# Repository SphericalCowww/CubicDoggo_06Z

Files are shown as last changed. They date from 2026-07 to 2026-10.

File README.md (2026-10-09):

# CubicDoggo 06Z: Homemade 12-DOF 4-Legged Robot Recipe with Simulation and Reinforcement Learning

Cubic Doggo 06Z Neucommu is upgraded from [Cubic Doggo 06R High Mobility](https://github.com/SphericalCowww/CubicDoggo_06R). The goal is to integrate a simulation (Gazebo/Mujoco) and reinforcement learning (PyTorch) to control walking gait. 

Demos: Gazebo with Plotjuggler ([Reddit](https://www.reddit.com/r/ROS/comments/1vomb40/cubic_doggo_update_on_gazebo/)), Gazebo sim vs real ([Reddit](https://www.reddit.com/r/robotics/comments/1vpu2sd/cubic_doggo_found_a_nice_spot_on_the_ramp/)), MuJoCo sim ([Reddit](https://www.reddit.com/r/ROS/comments/1w8vm74/cubic_doggo_update_ros2_bridge_to_mujoco/), Pinocchio walk ([Reddit](https://www.reddit.com/r/robotics/comments/1wgilv9/cubic_doggo_ik_walking_with_pinocchio/)

## Moment of inertia from FreeCAD

To get the moment of inertia for a FreeCAD piece, run,

    # open FreeCAD > View > Panels > Python console
    obj = App.ActiveDocument.getObject("Body")
    shape = obj.Shape
    print(shape.Mass)
    print(shape.CenterOfMass)
    print(shape.MatrixOfInertia)

Then use this formula to convert to URDF value for each matrix element (I: moment of inertia, M: mass):

    I_urdf = I_freeCAD*(M_physical/M_freeCAD)*1.0E-6

The convex mesh can also be included for collision geometry; check out ``batteryHolder`` under ``CubicDoggo_06Z/src/my_robot_description/urdf/cubic_doggo.gazebo.xacro``.

Don't forget to check the basic geometry under rViz first:

    cd CubicDoggo_06Z
    colcon build
    source install/setup.bash
    ros2 launch my_robot_description cubic_doggo.rviz.launch.xacro.py

## Gazebo

To have a window for keyboard control:

    sudo apt install xterm

Reminder that ``~/.gz/sim/8/gui.config``contains GUI display options, such as camera location. Then run:

    cd CubicDoggo_06Z
    colcon build
    source install/setup.bash
    ros2 launch my_robot_bringup cubic_doggo.gazebo.with_lifecycle.launch.py
    ros2 run plotjuggler plotjuggler      # on another terminal

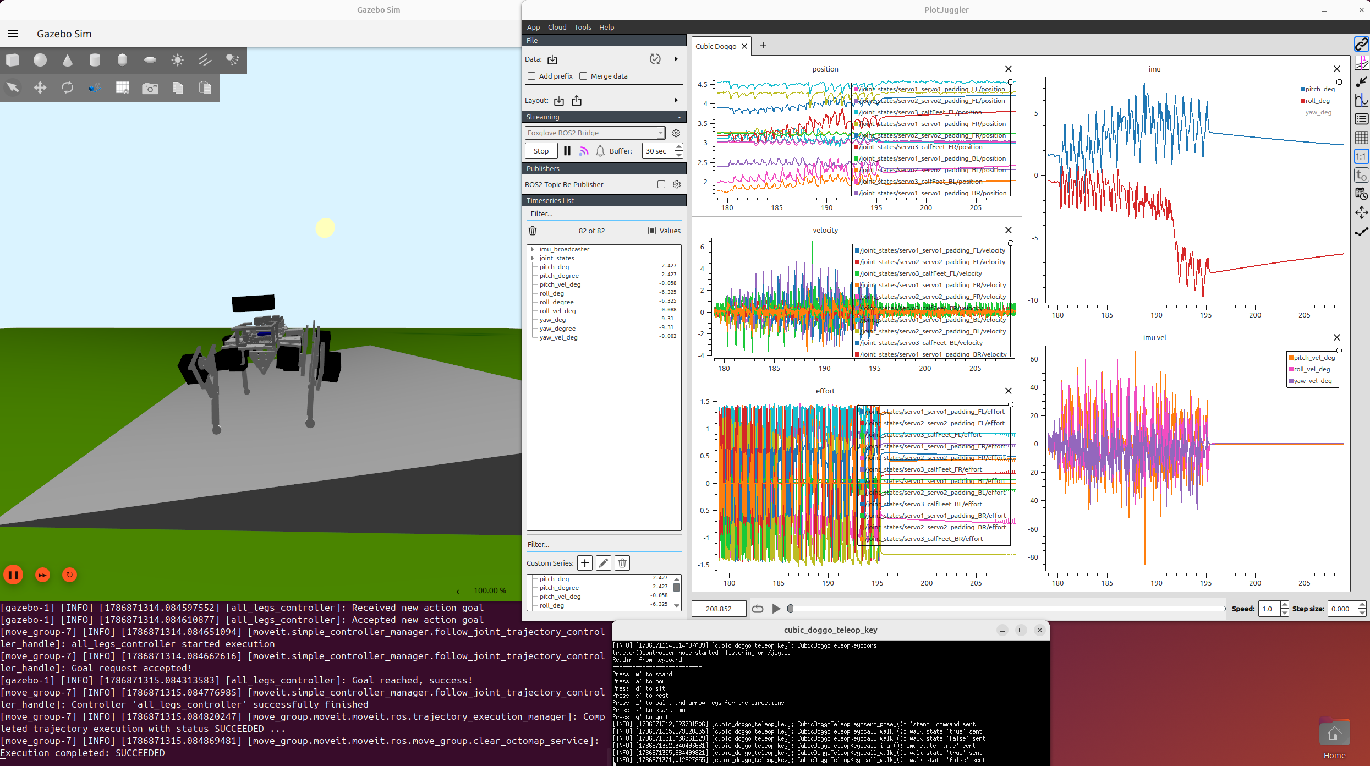
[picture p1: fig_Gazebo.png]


In the figure, the robot walks up the ramp, stands, turns on the IMU, walks with IMU, and then just stands with IMU on:

  * top-left: Gazebo graphics
  * top-right: plotjuggler
    * left: all 12 servo positions, velocities, and loads set to 1.5N limit
    * right: IMU values (PID control to make roll (tilt left-sideways) and pitch (tilt backward) to 0) and their velocities
  * bottom-left: launch terminal outputs
  * bottom-center: xterm control command window

Adding the following line of 20 ms delay in IMU does cause oscillatory behavior in Gazebo sometimes (turn off for real robot!):

    vim CubicDoggo_06Z/src/my_robot_commander/src/cubic_doggo_lifecycle_imu.cpp 
    # std::this_thread::sleep_for(std::chrono::milliseconds(20)); // WARNING: deliberate delay for simulation!!!

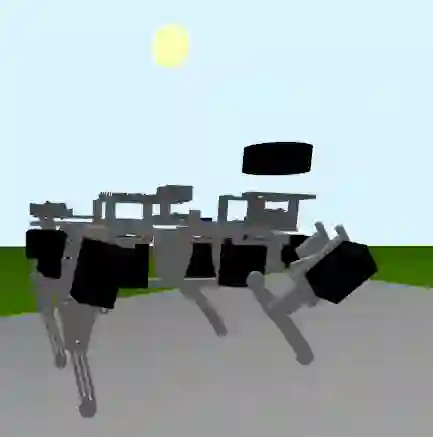
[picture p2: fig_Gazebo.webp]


## PyBullet

    cd CubicDoggo_06Z/
    cd ..                                                              # do NOT make the CubicDoggo_06Z_env/ inside CubicDoggo_06Z/, it will mess up colcon build
    python3 -m venv CubicDoggo_06Z_env/
    source CubicDoggo_06Z_env/bin/activate
    pip install --upgrade pip
    pip install "numpy<2"
    pip install setuptools jinja2 pyyaml typeguard
    pip install pybullet 
    pip install pin                                                     # for pinocchio
    pip install torch gymnasium stable-baselines3
    python3 -c "import torch; import pinocchio; import pybullet; import stable_baselines3; print('Installation Successful')"
    cd CubicDoggo_06Z/
    colcon build
    source install/setup.bash

Halfway through, realized MuJoCo is the modern way for robot simulation in python with CPU.

## MuJoCo

MuJoCo is a physics simulator like Gazebo,

    cd CubicDoggo_06Z/
    cd ..                                                                # do NOT create the CubicDoggo_06Z_env/ inside CubicDoggo_06Z/, it will mess up colcon build
    python3 -m venv CubicDoggo_06Z_env/
    source CubicDoggo_06Z_env/bin/activate
    export PYTHONPATH=$PYTHONPATH:.../CubicDoggo_06Z_env/lib/python3.12/site-packages     # put it in .bashrc
    export PYTHONPATH=$PYTHONPATH:.../CubicDoggo_06Z_env/lib/python3.12/site-packages/cmeel.prefix/lib/python3.12/site-packages
    pip install --upgrade pip 
    pip install catkin_pkg empy lark
    pip install jinja2 pyyaml typeguard setuptools wheel
    pip install mujoco pin gymnasium torch stable-baselines3 tensorboard            # pin for pinocchio
    pip install onnx onnxscript onnxruntime
    pip install --upgrade opencv-python
    python3 -c "import mujoco; import pinocchio; import gymnasium; import torch; import stable_baselines3; print('Installation Successful')"
    cd CubicDoggo_06Z/
    rm -r install/ build/ log/
    colcon build
    source install/setup.bash

### Launch MuJoCo with ROS2

To have 1 leg for the MuJoCo test, run:

    cd CubicDoggo_06Z/
    source ../CubicDoggo_06Z_env/bin/activate
    colcon build --cmake-clean-first
    source install/setup.bash
    ros2 run my_robot_commander_py cubic_leg1_mujoco_init
    # toggle 1 for visual, and toggle 0 for collision
    # expand control on the right-hand side to change joint values

To have the full robot with IMU as output, run:

    ros2 run my_robot_commander_py cubic_doggo_mujoco_init

To launch with commander/controller:
    
    ros2 launch my_robot_commander_py cubic_doggo.mujoco.with_lifecycle.launch.py
    ros2 run plotjuggler plotjuggler      # on another terminal

Note that this ROS2 to MuJoCo bridge does not use mujoco_ros2_control, but action server and joint state publisher instead. The reaction should rightfully be slower and less deterministic, but MuJoCo is plenty fast that its speed actually needs to be tuned by actuator PID under ``CubicDoggo_06Z/src/my_robot_description/urdf/cubic_doggo.mujoco.xml``.

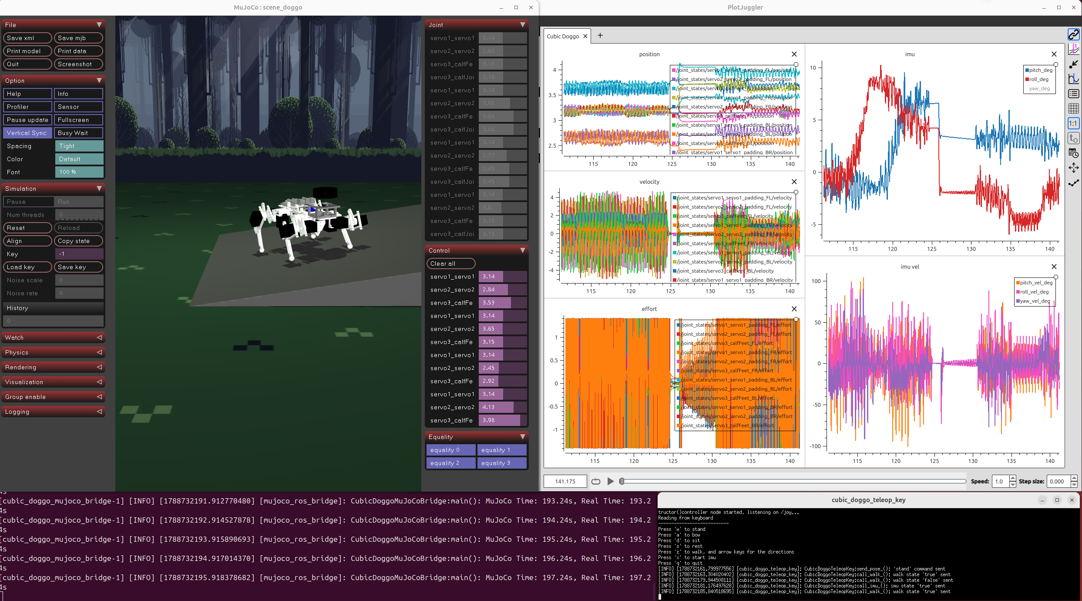
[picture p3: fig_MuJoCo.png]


Using the same ROS2 commander as for Gazebo.

### Launch MuJoCo with Pinocchio

Pinocchio is used as an IK solver to generate a predefined walk gait for later imitation learning,

    cd CubicDoggo_06Z/
    source ../CubicDoggo_06Z_env/bin/activate
    colcon build --cmake-clean-first
    source install/setup.bash
    ros2 run my_robot_commander_py cubic_doggo_mujoco_pin_stand_test
    ros2 run my_robot_commander_py cubic_doggo_mujoco_pin_walk
    ros2 run my_robot_commander_py cubic_doggo_mujoco_pin_stand

### Reinforcement learning with Gymnasium and stable-baselines3

Gymnasium sets up the environment for reinforcement learning, while stable-baselines3 provides the PPO optimization method for the reward/penalty terms from Gymnasium,

    cd CubicDoggo_06Z/
    source ../CubicDoggo_06Z_env/bin/activate
    colcon build --cmake-clean-first
    source install/setup.bash
    ros2 run cubic_doggo_mujoco_ppo_stand_train_kinematicHeight
    tensorboard --logdir=ppo_tensorboards
    # open in browser: http://localhost:6006

### Deploying model to MuJoCo

    cd CubicDoggo_06Z/
    source ../CubicDoggo_06Z_env/bin/activate
    colcon build --cmake-clean-first
    source install/setup.bash
    ros2 run my_robot_commander_py cubic_doggo_mujoco_ppo_stand_deploy

## References:

- CFD Intech, FreeCAD Tutorial | Exercise 6: How to Calculate Moment of Inertia of Model and Paste to Spreadsheet (<a href="https://www.youtube.com/watch?v=h6S0lKXxD3s">YouTube</a>)
- Edan Meyer | Proximal Policy Optimization (PPO) Explained ([YouTube](https://www.youtube.com/watch?v=HrapVFNBN64))

## Acknowledgements

- Some utility programs are adapted from the ROBOTIS DYNAMIXEL [Workbench examples](https://github.com/ROBOTIS-GIT/dynamixel-workbench/tree/main/dynamixel_workbench_toolbox/examples/sr) and [U2D2 Controller CAD](https://en.robotis.com/service/downloadpage.php?ca_id=70f0#). These files remain licensed under the Apache License 2.0. Modifications are documented in the source files.
- Raspberry Pi 5 CAD model sourced from [Printables](https://www.printables.com/model/607854-raspberry-pi-5).
- RPLIDAR A1M8 CAD model provided by [SLAMTEC](https://www.slamtec.com/en/support#rplidar-a-series).
- Forest background used in MuJoCo, "Free Pixel Art Forest" by edermuniz14 from [GameDev Market](https://www.gamedevmarket.net/asset/free-pixel-art-forest). Used under the GameDev Market Pro Licence.
- 8-bit AI-generated music by Retro-BGM-Chan from [Pixabay](https://pixabay.com/users/retro-bgm-chan-55246343/). Used under the [Pixabay License](https://pixabay.com/service/license-summary/)
- 8-bit AI-generated music by Brutaldesign from [Pixabay](https://pixabay.com/users/brutaldesign-52522998). Used under the [Pixabay License](https://pixabay.com/service/license-summary/)
- 8-bit AI-generated music by Psychronic from [Pixabay](https://pixabay.com/users/psychronic-13092015). Used under the [Pixabay License](https://pixabay.com/service/license-summary/)

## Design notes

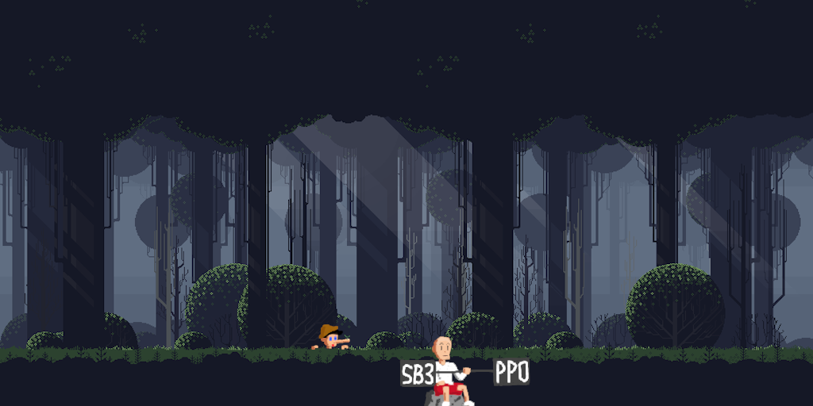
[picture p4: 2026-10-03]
src/my_robot_description/world/forest_gymnasium.png

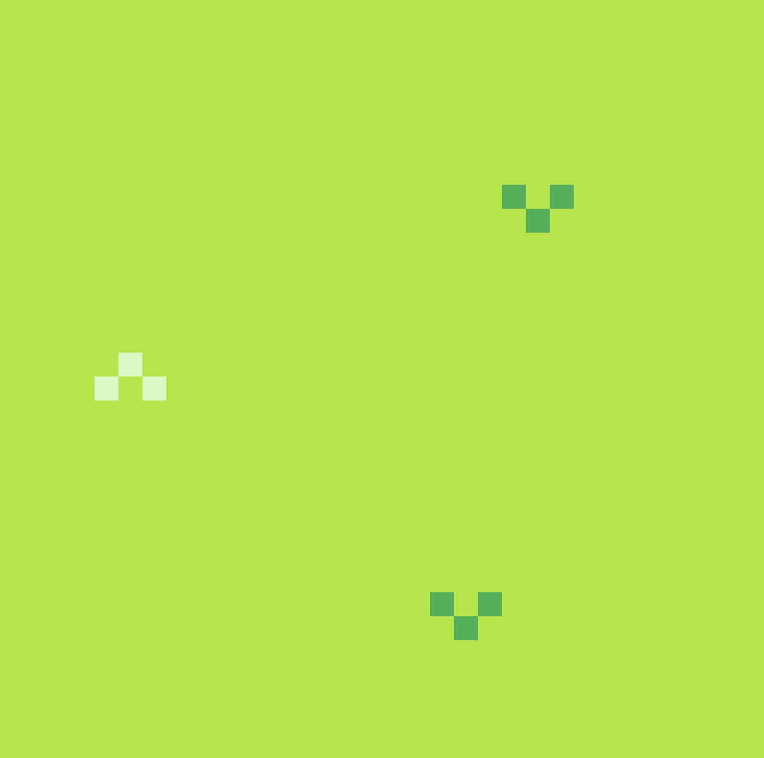
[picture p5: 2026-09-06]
src/my_robot_description/world/grass.png

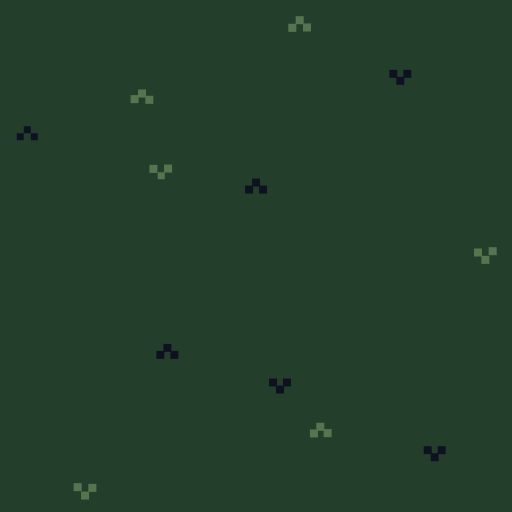
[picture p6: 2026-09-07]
src/my_robot_description/world/forest_floor.png

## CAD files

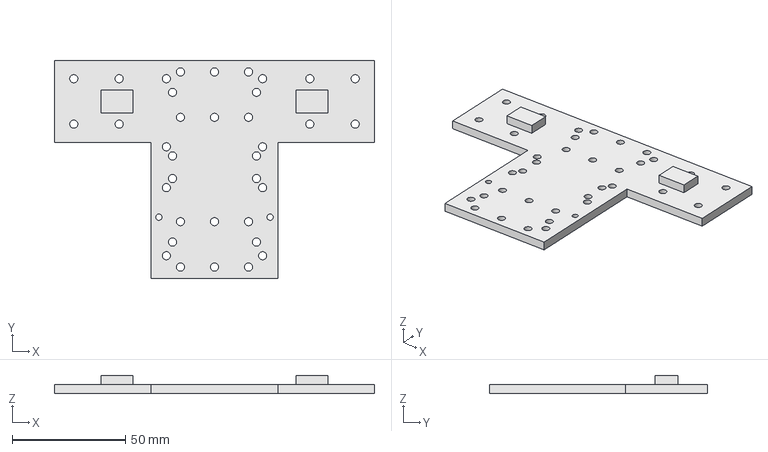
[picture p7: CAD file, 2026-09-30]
src/my_robot_description/mesh/CADv3/basePlate.FCStd
141.0 x 96.0 x 8.00 mm

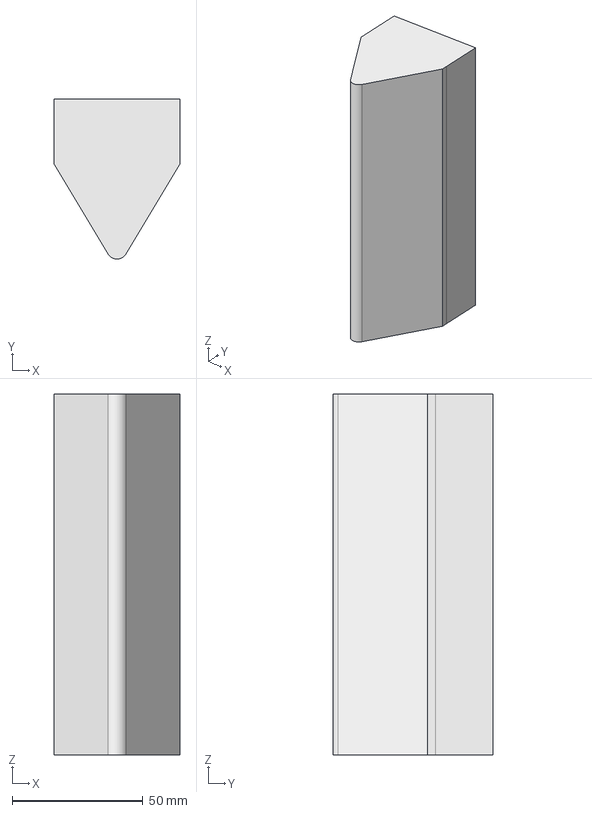
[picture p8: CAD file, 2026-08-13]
src/my_robot_description/mesh/collisionV3/batteryHolder.FCStd
48.0 x 61.2 x 138.0 mm

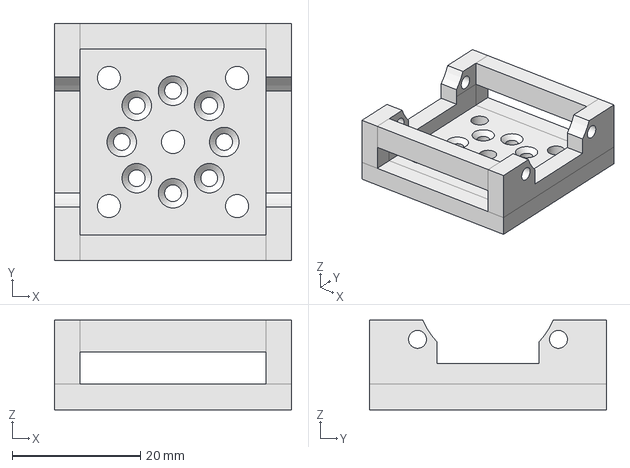
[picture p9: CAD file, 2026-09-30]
src/my_robot_description/mesh/CADv3/XL430holderBasic.FCStd
37.0 x 37.0 x 14.0 mm

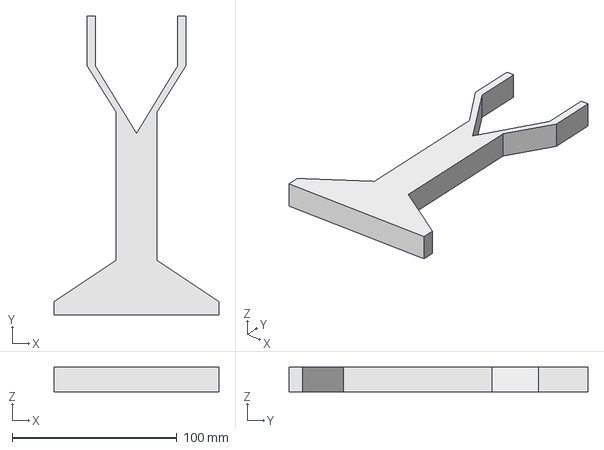
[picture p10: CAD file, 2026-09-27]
src/my_robot_description/mesh/CADv3/bodyHolder.FCStd
100.0 x 181.0 x 15.0 mm

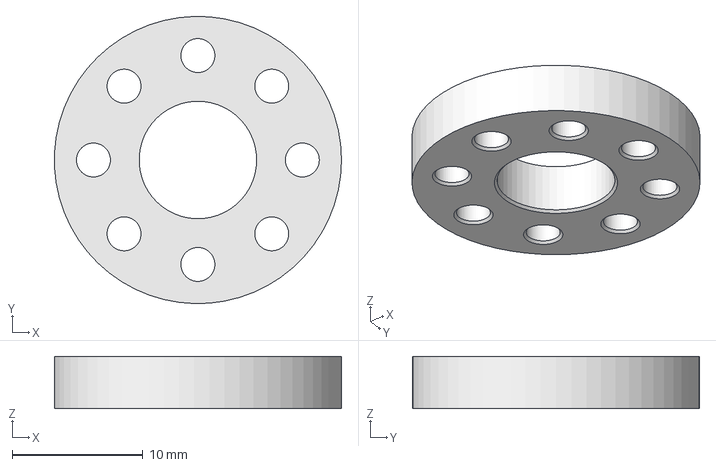
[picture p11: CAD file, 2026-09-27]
src/my_robot_description/mesh/CADv3/XL430rotorPadding.FCStd
22.0 x 22.0 x 4.00 mm

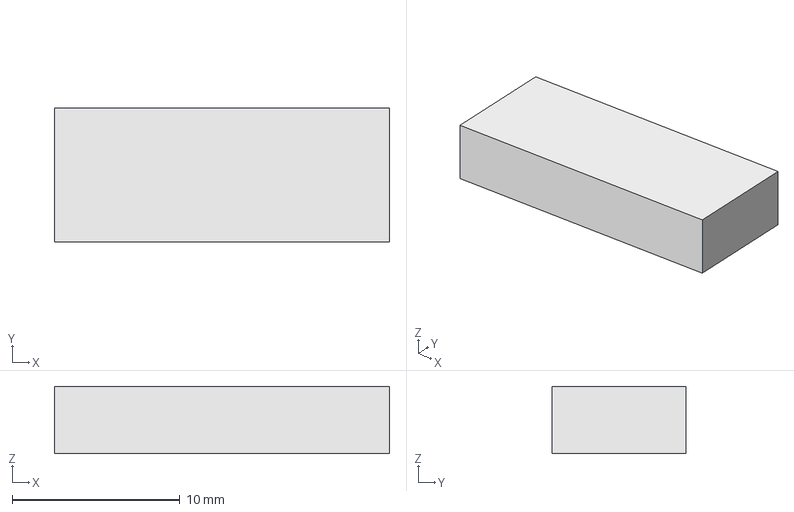
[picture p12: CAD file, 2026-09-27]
src/my_robot_description/mesh/CADv3/baseSticker.FCStd
20.0 x 8.00 x 4.00 mm

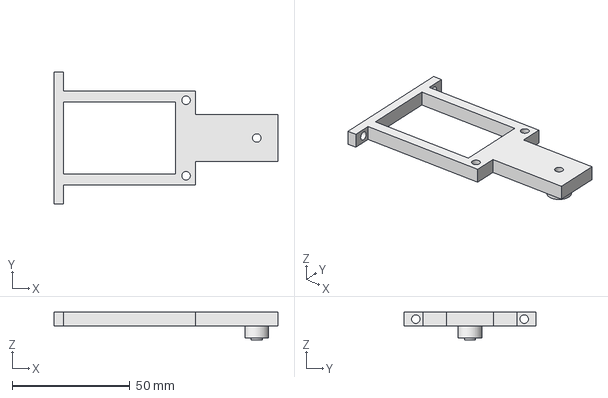
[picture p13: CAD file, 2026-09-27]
src/my_robot_description/mesh/CADv3/thighOuter.FCStd
95.0 x 56.0 x 11.8 mm

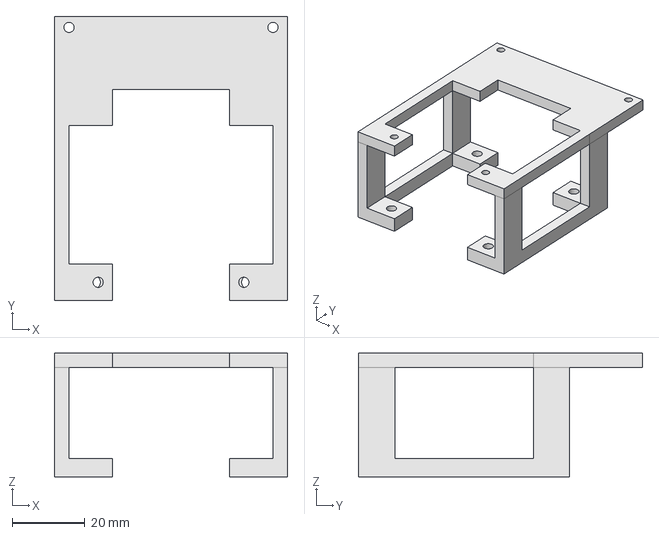
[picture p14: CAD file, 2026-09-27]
src/my_robot_description/mesh/CADv3/lidarHolder.FCStd
64.0 x 78.0 x 34.0 mm

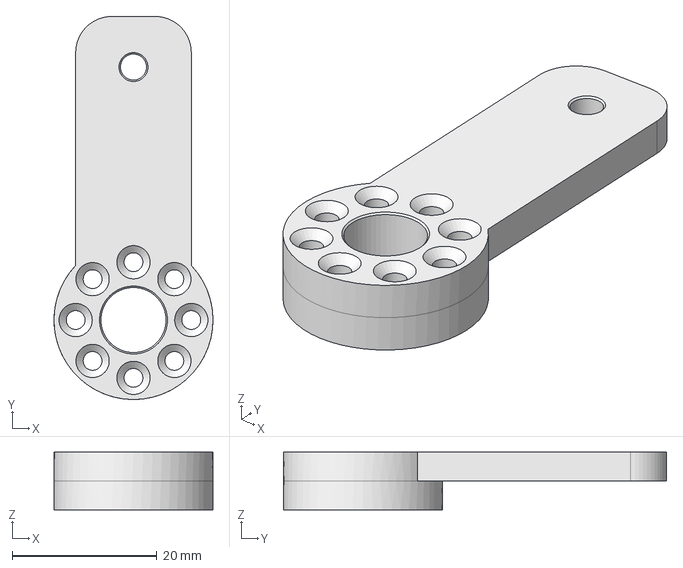
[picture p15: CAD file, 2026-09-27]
src/my_robot_description/mesh/CADv3/calfJoint.FCStd
22.0 x 53.0 x 8.00 mm

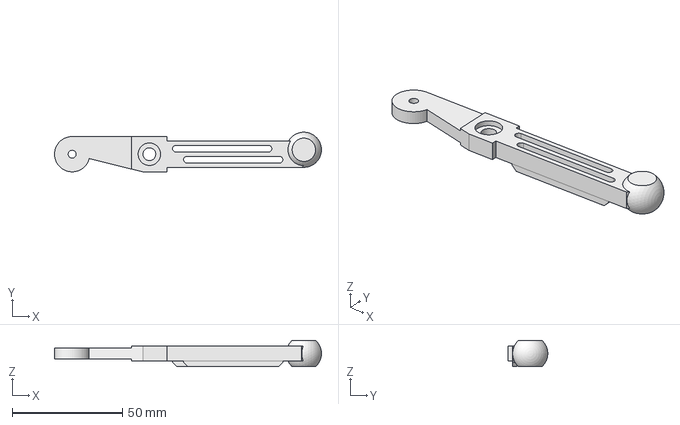
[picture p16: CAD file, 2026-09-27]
src/my_robot_description/mesh/CADv3/calfFeet.FCStd
121.0 x 18.0 x 12.0 mm

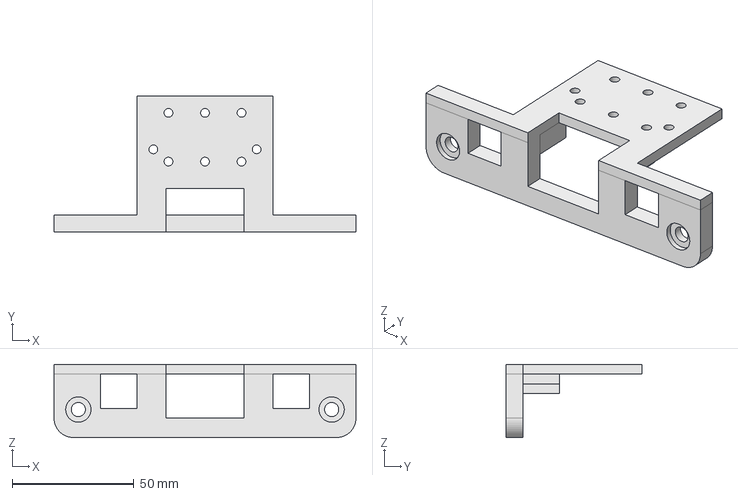
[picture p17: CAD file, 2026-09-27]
src/my_robot_description/mesh/CADv3/bearingPlate.FCStd
124.0 x 56.0 x 30.0 mm

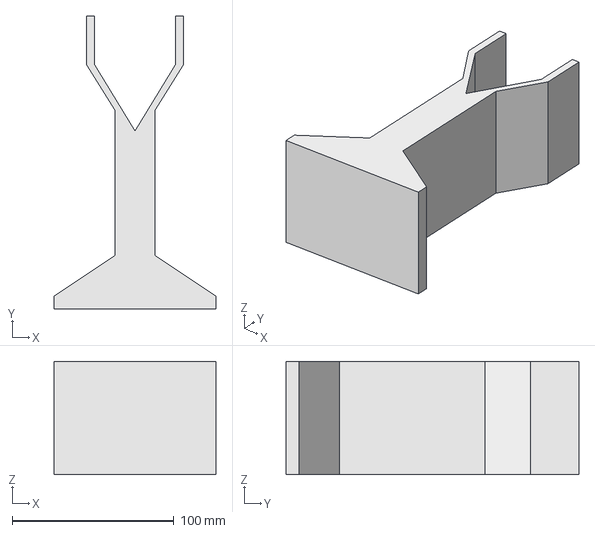
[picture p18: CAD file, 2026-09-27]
src/my_robot_description/mesh/CADv3/bodyHolderWide.FCStd
100.0 x 181.0 x 70.0 mm

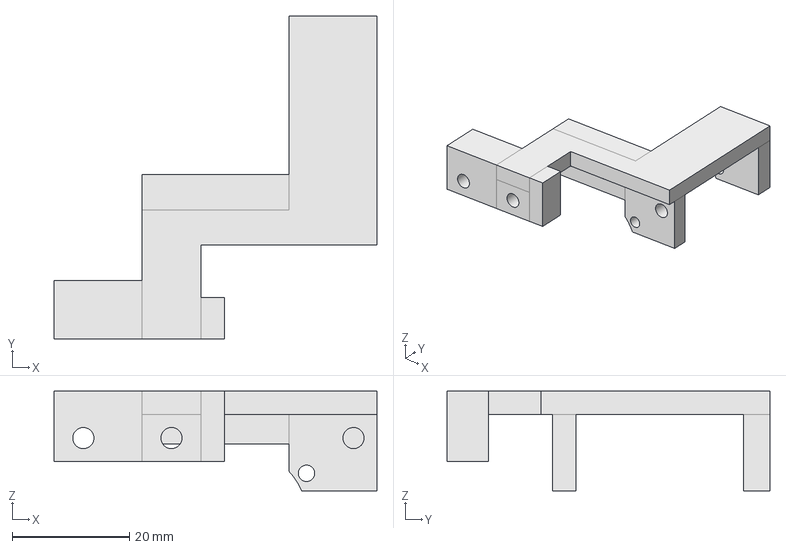
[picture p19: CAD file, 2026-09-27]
src/my_robot_description/mesh/CADv3/XL430holderThighBack.FCStd
55.0 x 55.0 x 17.0 mm

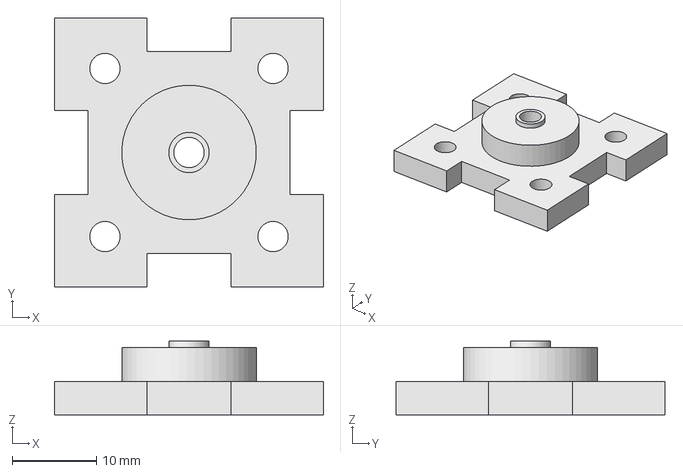
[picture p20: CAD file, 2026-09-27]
src/my_robot_description/mesh/CADv3/bearingPadding.FCStd
32.0 x 32.0 x 8.80 mm

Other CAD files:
src/my_robot_description/mesh/CADv3/thighInner.FCStd
src/my_robot_description/mesh/CADv3/fanFlag.FCStd
src/my_robot_description/mesh/CADv3/baseTorso.FCStd
src/my_robot_description/mesh/CADv3/XL430holderBasic.stl
src/my_robot_description/mesh/CADv3/XL430holderThighFront.FCStd
src/my_robot_description/mesh/CADv3/XL430rotorPadding.stl
src/my_robot_description/mesh/CADv3/basePlate.stl
src/my_robot_description/mesh/CADv3/baseTorso.stl
src/my_robot_description/mesh/CADv3/batteryHolder.FCStd
src/my_robot_description/mesh/CADv3/batteryHolder.stl
src/my_robot_description/mesh/CADv3/calfFeet.stl
src/my_robot_description/mesh/CADv3/calfFeetSpring.stl
src/my_robot_description/mesh/CADv3/calfJoint.stl
src/my_robot_description/mesh/CADv3/hdmiHolder.FCStd
src/my_robot_description/mesh/CADv3/lidarHolder.stl
src/my_robot_description/mesh/CADv3/thighInner.stl
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

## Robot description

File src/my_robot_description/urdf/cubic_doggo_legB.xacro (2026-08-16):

<?xml version="1.0"?>
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
<robot xmlns:xacro="http://www.ros.org/wiki/xacro">
    <xacro:macro name="doggo_legB" params="prefix">

    <xacro:property name="servo_x" value="0.0285"/>
    <xacro:property name="servo_y" value="0.0465"/>
    <xacro:property name="servo_z" value="0.034"/>
    <xacro:if value="${prefix == 'BL'}">
        <xacro:property name="rflc" value="-1"/>
        <xacro:property name="base_plate" value='base_plate_B'/>
        <xacro:property name="servo1_holder_xyz" value=" 0.052 0.018 0.004"/>
    </xacro:if>
    <xacro:if value="${prefix == 'BR'}">
        <xacro:property name="rflc" value=" 1"/>
        <xacro:property name="base_plate" value='base_plate_B'/>
        <xacro:property name="servo1_holder_xyz" value="-0.052 0.018 0.004"/>
    </xacro:if> 
    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
    <link name="servo1_holder_${prefix}">
        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
        <xacro:box_inertia m="0.0098" x="0.037" y="0.037" z="0.014" o_xyz="0 0 0.007" o_rpy="0 0 ${urdf_pi/2}"/>
    </link> 
    <joint name="base_plate_servo1_holder_${prefix}" type="fixed">
        <parent link="${base_plate}"/>
        <child link="servo1_holder_${prefix}"/>
        <origin xyz="${servo1_holder_xyz}" rpy="0 0 0"/>
    </joint>
    
    <link name="servo1_${prefix}">
        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
        <xacro:box_inertia m="0.0572" x="${servo_x}" y="${servo_y}" z="${servo_z}" o_xyz="0 0 ${servo_y/2}" o_rpy="${urdf_pi/2} 0 0"/>
    </link> 
    <joint name="servo1_holder_servo1_${prefix}" type="fixed">
        <parent link="servo1_holder_${prefix}"/>
        <child link="servo1_${prefix}"/>
        <origin xyz="0 0 0.008" rpy="0 0 0"/>
    </joint>

    <link name="servo1_padding_${prefix}">
        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
        <xacro:cylinder_inertia m="0.0013" r="0.011" l="0.004" o_xyz="0 -0.002 0" o_rpy="${urdf_pi/2} 0 0"/>
    </link> 
    <joint name="servo1_servo1_padding_${prefix}" type="revolute">
        <parent link="servo1_${prefix}"/>
        <child link="servo1_padding_${prefix}"/>
        <origin xyz="0 ${-servo_z/2-0.002} ${0.01+0.0025/2}" rpy="0 0 0"/>
        <axis xyz="0 -1 0"/>
        <limit effort="1.4" velocity="10.0" lower="${urdf_pi - urdf_pi/3}" upper="${urdf_pi + urdf_pi/3}"/>
        <dynamics friction="0.01" damping="0.1"/>
    </joint>

    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
    <link name="servo2_holder_${prefix}">
        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
        <xacro:box_inertia m="0.0098" x="0.037" y="0.037" z="0.014" o_xyz="0 -0.007 0" o_rpy="${urdf_pi/2} 0 0"/>
    </link> 
    <joint name="base_link_servo2_holder_${prefix}" type="fixed">
        <parent link="servo1_padding_${prefix}"/>
        <child link="servo2_holder_${prefix}"/>
        <origin xyz="0 -0.004 0" rpy="0 0 0"/>
    </joint>
    
    <link name="servo2_${prefix}">
        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
        <xacro:box_inertia m="0.0572" x="${servo_x}" y="${servo_y}" z="${servo_z}" o_xyz="0 ${-servo_y/2} 0" o_rpy="0 ${rflc*urdf_pi/2} 0"/>
    </link> 
    <joint name="servo2_holder_servo2_${prefix}" type="fixed">
        <parent link="servo2_holder_${prefix}"/>
        <child link="servo2_${prefix}"/>
        <origin xyz="0 -0.008 0" rpy="0 0 0"/>
    </joint>

    <link name="servo2_padding_${prefix}">
        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
        <xacro:cylinder_inertia m="0.0013" r="0.011" l="0.004" o_xyz="${rflc*0.002} 0 0" o_rpy="0 ${urdf_pi/2} 0"/>
    </link> 
    <joint name="servo2_servo2_padding_${prefix}" type="revolute">
        <parent link="servo2_${prefix}"/>
        <child link="servo2_padding_${prefix}"/>
        <origin xyz="${rflc*(servo_z/2+0.002)} -0.01125 0" rpy="0 0 0"/>
        <axis xyz="${rflc} 0 0"/>
        <limit effort="1.4" velocity="10.0" lower="${urdf_pi - 2*urdf_pi/6 + rflc*urdf_pi/6}" upper="${urdf_pi + 2*urdf_pi/6 + rflc*urdf_pi/6}"/>
        <dynamics friction="0.01" damping="0.1"/>
    </joint>

    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
    <link name="inner_thigh_${prefix}">
        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
        <xacro:box_inertia m="0.0085" x="0.032" y="0.040" z="0.006" o_xyz="${rflc*0.003} -0.016 0" o_rpy="${rflc*urdf_pi/2} 0 ${urdf_pi/2}"/>
    </link>
    <joint name="servo2_padding_inner_thigh_${prefix}" type="fixed">
        <parent link="servo2_padding_${prefix}"/>
        <child link="inner_thigh_${prefix}"/>
        <origin xyz="${rflc*0.004} -0.016 0" rpy="0 0 0"/>
    </joint>

    <link name="outer_thigh_${prefix}">
        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
        <xacro:box_inertia m="0.0113" x="0.040" y="0.032" z="0.006" o_xyz="${rflc*0.003} 0.0475 0" o_rpy="${-urdf_pi/2} ${urdf_pi/2-rflc*urdf_pi/2} ${-rflc*urdf_pi/2}"/>
    </link>
    <joint name="inner_thigh_outer_thigh_${prefix}" type="fixed">
        <parent link="inner_thigh_${prefix}"/>
        <child link="outer_thigh_${prefix}"/>
        <origin xyz="${rflc*0.028} 0 0" rpy="${urdf_pi} 0 0"/>
    </joint>

    <link name="servo3_${prefix}">
        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
        <xacro:box_inertia m="${0.0572+0.0113+0.0078}" x="${servo_x}" y="${servo_y}" z="${servo_z}" o_xyz="0 ${-servo_y/2} 0" o_rpy="0 ${rflc*urdf_pi/2} 0"/>
    </link>
    <joint name="outer_thigh_servo3_${prefix}" type="fixed">
        <parent link="outer_thigh_${prefix}"/>
        <child link="servo3_${prefix}"/>
        <origin xyz="${rflc*(servo_y/2-0.006-0.0025)} -0.004 0" rpy="0 0 0"/>
    </joint>

    <link name="calfFeet_${prefix}">
        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
        <xacro:box_inertia m="${0.0251-0.0080}" x="0.110" y="0.016" z="0.004" o_xyz="0 ${-0.008+0.008} ${0.035-0.050}" o_rpy="0 ${-urdf_pi/2} 0"/>
    </link>
    <joint name="servo3_calfFeet_${prefix}" type="revolute">
        <parent link="servo3_${prefix}"/>
        <child link="calfFeet_${prefix}"/>
        <origin xyz="${rflc*(-servo_z/2-0.002-0.0025)} ${-0.086+0.004} 0" rpy="${urdf_pi} 0 0"/>
        <axis xyz="${-rflc} 0 0"/>
        <limit effort="1.4" velocity="10.0" lower="${5*urdf_pi/8}" upper="${11*urdf_pi/8}"/>
        <dynamics friction="0.01" damping="0.1"/>
    </joint>

    <link name="calfJoint_${prefix}">
        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
        <xacro:box_inertia m="${0.0047+0.0015}" x="0.022" y="0.053" z="0.007" o_xyz="${-rflc*0.0005} 0 -0.0155" o_rpy="${-urdf_pi/2} 0 ${-rflc*urdf_pi/2}"/>
    </link>
    <joint name="servo3_calfJoint_${prefix}" type="revolute">
        <parent link="servo3_${prefix}"/>
        <child link="calfJoint_${prefix}"/>
        <origin xyz="${rflc*(-servo_z/2-0.002-0.0025)} ${-0.01-0.0025/2} 0" rpy="0 0 0"/>
        <axis xyz="${-rflc} 0 0"/>
        <mimic joint="servo3_calfFeet_${prefix}" multiplier="1.0" offset="0.0"/>
        <limit effort="1.4" velocity="10.0" lower="${5*urdf_pi/8}" upper="${11*urdf_pi/8}"/>
        <dynamics friction="0.01" damping="0.1"/>
    </joint>

    <link name="calfSphere_${prefix}">
        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
        <xacro:sphere_inertia m="0.004" r="0.008" o_xyz="0 0 0" o_rpy="0 0 0"/>
    </link>
    <joint name="calfFeet_calfSphere_${prefix}" type="fixed">
        <parent link="calfFeet_${prefix}"/>
        <child link="calfSphere_${prefix}"/>
        <origin xyz="0 -0.002 ${-0.105+0.035}" rpy="0 0 0"/>
    </joint>
    </xacro:macro>
</robot>
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

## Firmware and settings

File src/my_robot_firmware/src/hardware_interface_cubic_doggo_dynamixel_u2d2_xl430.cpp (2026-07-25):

#include <iostream>
#include <chrono>
#include <thread>
#include "rclcpp/rclcpp.hpp"
#include "my_robot_firmware/hardware_interface_cubic_doggo_dynamixel_u2d2_xl430.hpp"

//////////////////////////////////////////////////////////////////////////////////////////////////////////////////////
namespace cubic_doggo_namespace {
    hardware_interface::CallbackReturn HardwareInterfaceU2D2_cubic_doggo::on_init(
        const hardware_interface::HardwareComponentInterfaceParams &params) 
    {
        if (hardware_interface::SystemInterface::on_init(params) != hardware_interface::CallbackReturn::SUCCESS) {
            return hardware_interface::CallbackReturn::ERROR;
        }
        RCLCPP_INFO(get_logger(), "hardware_interface:on_init()");

        try {
            port_name_ = params.hardware_info.hardware_parameters.at("port_name");
            baud_rate_ = std::stoi(params.hardware_info.hardware_parameters.at("baud_rate"));
        } catch (const std::out_of_range& errorMsg) {
            RCLCPP_ERROR(get_logger(), "hardware_interface:on_init(): missing required parameter in URDF");
            return hardware_interface::CallbackReturn::ERROR;
        }
        RCLCPP_INFO(get_logger(), "hardware_interface:on_init(): "
                                  "dynamixel opening port %s at %d baud", port_name_.c_str(), baud_rate_);
        dxl_return_ = dxl_wb_.init(port_name_.c_str(), baud_rate_, &log_);
        if (dxl_return_ == false) {
            RCLCPP_ERROR(get_logger(),"hardware_interface:on_init(): failed to open the port %s!",port_name_.c_str());
            return hardware_interface::CallbackReturn::ERROR;
        } else {
            RCLCPP_INFO(get_logger(), "hardware_interface:on_init(): initialize with baud rate: %d", baud_rate_);
        } 


        /////////// see: src/my_robot_description/urdf/cubic_doggo.ros2_control.xacro
        servo_channels_[0]  = std::stoi(params.hardware_info.hardware_parameters.at("servo1_channel_FL"));
        servo_channels_[1]  = std::stoi(params.hardware_info.hardware_parameters.at("servo2_channel_FL"));
        servo_channels_[2]  = std::stoi(params.hardware_info.hardware_parameters.at("servo3_channel_FL"));
        servo_channels_[3]  = std::stoi(params.hardware_info.hardware_parameters.at("servo1_channel_FR"));
        servo_channels_[4]  = std::stoi(params.hardware_info.hardware_parameters.at("servo2_channel_FR"));
        servo_channels_[5]  = std::stoi(params.hardware_info.hardware_parameters.at("servo3_channel_FR"));
        servo_channels_[6]  = std::stoi(params.hardware_info.hardware_parameters.at("servo1_channel_BL"));
        servo_channels_[7]  = std::stoi(params.hardware_info.hardware_parameters.at("servo2_channel_BL"));
        servo_channels_[8]  = std::stoi(params.hardware_info.hardware_parameters.at("servo3_channel_BL"));
        servo_channels_[9]  = std::stoi(params.hardware_info.hardware_parameters.at("servo1_channel_BR"));
        servo_channels_[10] = std::stoi(params.hardware_info.hardware_parameters.at("servo2_channel_BR"));
        servo_channels_[11] = std::stoi(params.hardware_info.hardware_parameters.at("servo3_channel_BR"));
        joint_names = {"servo1_servo1_padding_FL", 
                       "servo2_servo2_padding_FL", 
                       "servo3_calfFeet_FL",
                       "servo1_servo1_padding_FR",
                       "servo2_servo2_padding_FR",
                       "servo3_calfFeet_FR",
                       "servo1_servo1_padding_BL",
                       "servo2_servo2_padding_BL",
                       "servo3_calfFeet_BL",
                       "servo1_servo1_padding_BR",
                       "servo2_servo2_padding_BR",
                       "servo3_calfFeet_BR"};
        rad_positions_init_[0]  = 3.14;                      
        rad_positions_init_[1]  = 2.54;                      //DXL_PI - DXL_PI/4.0;
        rad_positions_init_[2]  = 4.14;                      //DXL_PI - DXL_PI/8.0;
        rad_positions_init_[3]  = 3.14;                      
        rad_positions_init_[4]  = 3.74;                      //DXL_PI + DXL_PI/4.0;
        rad_positions_init_[5]  = 2.14;                      //DXL_PI + DXL_PI/8.0;
        rad_positions_init_[6]  = 3.14;                     
        rad_positions_init_[7]  = 2.54;                      //DXL_PI - DXL_PI/4.0;
        rad_positions_init_[8]  = 4.14;                      //DXL_PI - DXL_PI/8.0;
        rad_positions_init_[9]  = 3.14;                      
        rad_positions_init_[10] = 3.74;                      //DXL_PI + DXL_PI/4.0;
        rad_positions_init_[11] = 2.14;                      //DXL_PI + DXL_PI/8.0;
        ///////////
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

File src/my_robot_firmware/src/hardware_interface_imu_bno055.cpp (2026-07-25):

#include <iostream>
#include <fcntl.h>
#include <sys/ioctl.h>
#include <linux/i2c-dev.h>
#include <unistd.h>
#include <cmath>
#include <chrono>
#include <thread>
#include "rclcpp/rclcpp.hpp"
#include "my_robot_firmware/hardware_interface_imu_bno055.hpp"

//////////////////////////////////////////////////////////////////////////////////////////////////////////////////////
namespace imu_namespace {
    hardware_interface::CallbackReturn HardwareInterfaceBNO055_imu::on_init(
        const hardware_interface::HardwareComponentInterfaceParams &params) 
    {
        if (hardware_interface::SensorInterface::on_init(params) != hardware_interface::CallbackReturn::SUCCESS) {
            return hardware_interface::CallbackReturn::ERROR;
        }
        RCLCPP_INFO(get_logger(), "hardware_interface_imu:on_init()");

        /////////// see: src/my_robot_description/urdf/cubic_doggo.ros2_control.xacro
        try {
            i2c_bus_     = params.hardware_info.hardware_parameters.at("i2c_bus");
            address_     = std::stoi(params.hardware_info.hardware_parameters.at("address"), nullptr, 16);
            reset_pin_   = std::stoi(params.hardware_info.hardware_parameters.at("reset_pin"));
            sensor_name_ = params.hardware_info.sensors[0].name;
        } catch (const std::out_of_range& errorMsg) {
            RCLCPP_ERROR(get_logger(), "hardware_interface_imu:on_init(): missing required parameter in URDF");
            return CallbackReturn::ERROR;
        }
        RCLCPP_INFO(get_logger(), "hardware_interface_imu:on_init(): parameters loaded");
        ///////////

        return hardware_interface::CallbackReturn::SUCCESS;     
    }
    hardware_interface::CallbackReturn HardwareInterfaceBNO055_imu::on_configure(
        const rclcpp_lifecycle::State& /*previous_state*/)  
    {
        RCLCPP_INFO(get_logger(), "hardware_interface_imu:on_configure()");
        
        gpio_chip_ = gpiod_chip_open_by_name("gpiochip4");
        if (!gpio_chip_) {
            RCLCPP_ERROR(get_logger(), "hardware_interface_imu:on_configure(): "
                                       "failed to open gpiochip4 (Pi 5 header)");
            return CallbackReturn::ERROR;
        }
 
        reset_line_ = gpiod_chip_get_line(gpio_chip_, reset_pin_);
        if (!reset_line_) {
            RCLCPP_ERROR(get_logger(), "hardware_interface_imu:on_configure(): "
                                       "failed to get reset line %d", reset_pin_);
            return CallbackReturn::ERROR;
        }
        gpiod_line_request_output(reset_line_, "bno_reset", 1);
        gpiod_line_set_value(reset_line_, 0);
        std::this_thread::sleep_for(std::chrono::milliseconds(100));
        gpiod_line_set_value(reset_line_, 1); 
        std::this_thread::sleep_for(std::chrono::milliseconds(700)); // wait for boot

        i2c_fd_ = open(i2c_bus_.c_str(), O_RDWR);
        if (i2c_fd_ < 0 || ioctl(i2c_fd_, I2C_SLAVE, address_) < 0) {
            RCLCPP_ERROR(get_logger(), "hardware_interface_imu:on_configure(): "
                                       "failed to open I2C bus or connect to 0x%02x", address_);
            return CallbackReturn::ERROR;
        }

        return hardware_interface::CallbackReturn::SUCCESS;
    }
    hardware_interface::CallbackReturn HardwareInterfaceBNO055_imu::on_activate(
        const rclcpp_lifecycle::State& /*previous_state*/)  
    {
        RCLCPP_INFO(get_logger(), "hardware_interface_imu:on_activate()");
       
        uint8_t config[2] = {0x3D, 0x0C}; 
        if (::write(i2c_fd_, config, 2) != 2) {
            RCLCPP_ERROR(get_logger(), "hardware_interface_imu:on_activate(): failed to set NDOF mode");
            return CallbackReturn::ERROR;
        }
        std::this_thread::sleep_for(std::chrono::milliseconds(50));

        return hardware_interface::CallbackReturn::SUCCESS;
    }
    hardware_interface::CallbackReturn HardwareInterfaceBNO055_imu::on_deactivate(
        const rclcpp_lifecycle::State & /*previous_state*/)  
    {
        RCLCPP_INFO(get_logger(), "hardware_interface_imu:on_deactivate()");

        uint8_t config[2] = {0x3D, 0x00};
        ::write(i2c_fd_, config, 2);

        return hardware_interface::CallbackReturn::SUCCESS;
    }
    HardwareInterfaceBNO055_imu::~HardwareInterfaceBNO055_imu() {
        if (i2c_fd_ >= 0) ::close(i2c_fd_);
        if (reset_line_)  gpiod_line_release(reset_line_);
        if (gpio_chip_)   gpiod_chip_close(gpio_chip_);
    }
//////////////////////////////////////////////////////////////////////////////////////////////////////////////////////
    hardware_interface::return_type HardwareInterfaceBNO055_imu::read(
        const rclcpp::Time & /*time*/, const rclcpp::Duration & /*period*/)
    {
        RCLCPP_DEBUG(get_logger(), "hardware_interface_imu:read()");

        uint8_t reg = 0x08;
        uint8_t data[44];

        if ((::write(i2c_fd_, &reg, 1) != 1) || (::read(i2c_fd_, data, 44) != 44)) {
            RCLCPP_WARN_THROTTLE(get_logger(), *get_clock(), 1000, "hardware_interface_imu:read():"
                                                                   "I2C Burst Read Failed");
            return hardware_interface::return_type::ERROR;
        }

        // linear acceleration in m/s^2
        imu_states_[0] = static_cast<int16_t>(data[33] << 8 | data[32]) / 100.0; // linear_acceleration.x
        imu_states_[1] = static_cast<int16_t>(data[35] << 8 | data[34]) / 100.0; // linear_acceleration.y
        imu_states_[2] = static_cast<int16_t>(data[37] << 8 | data[36]) / 100.0; // linear_acceleration.z
 
        // angular velocity in rad/s
        double dps_to_rads = M_PI / 180.0;
        imu_states_[3] = (static_cast<int16_t>(data[13] << 8 | data[12]) / 16.0) * dps_to_rads; // angular_velocity.x
        imu_states_[4] = (static_cast<int16_t>(data[15] << 8 | data[14]) / 16.0) * dps_to_rads; // angular_velocity.y
        imu_states_[5] = (static_cast<int16_t>(data[17] << 8 | data[16]) / 16.0) * dps_to_rads; // angular_velocity.z
    
        // orientation quaternion  
        double q_scale = 1.0 / 16384.0; // 2^14
        imu_states_[6] = static_cast<int16_t>(data[25] << 8 | data[24]) * q_scale; // orientation.w
        imu_states_[7] = static_cast<int16_t>(data[27] << 8 | data[26]) * q_scale; // orientation.x
        imu_states_[8] = static_cast<int16_t>(data[29] << 8 | data[28]) * q_scale; // orientation.y
        imu_states_[9] = static_cast<int16_t>(data[31] << 8 | data[30]) * q_scale; // orientation.z

        // euler angles (reg 0x1A-0x1F) 
        imu_states_[10] = static_cast<int16_t>(data[21] << 8 | data[20]) / 16.0; // roll
        imu_states_[11] = static_cast<int16_t>(data[23] << 8 | data[22]) / 16.0; // pitch
        imu_states_[12] = static_cast<int16_t>(data[19] << 8 | data[18]) / 16.0; // heading
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

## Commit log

2026-07-25 - initial commit
    [common_properties.xacro, cubic_doggo.ros2_control.xacro, cubic_doggo.urdf.xacro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]
2026-07-25 - turning off the IMU at the moment as the simulation/training cannot take place in rasp pi
    [cubic_doggo.ros2_control.xacro]
2026-07-25 - initial mock imu implemented
    [cubic_doggo.ros2_control.xacro]
2026-07-28 - adding files for launching gazebo
    [cubic_doggo.gazebo.xacro]
2026-08-01 - gazebo now renders, but has syncing problem
    [cubic_doggo.gazebo.xacro]
2026-08-01 - now the robot can walk in gazebo; don't need to sync the clock in simulation
    [cubic_doggo.gazebo.xacro]
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2026-08-01 - now starting with proper rest joint values
    [cubic_doggo.gazebo.xacro]
2026-08-09 - imu now in Gazebo, but doesn't seem to show up in plotjuggler
    [cubic_doggo.gazebo.xacro, cubic_doggo.urdf.xacro, cubic_doggo_controllers.yaml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]
2026-08-10 - some urdf geometry update - initial world building in gazebo
    [cubic_doggo_legB.xacro, cubic_doggo_legF.xacro, slope.sdf]
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2026-08-12 - adding better slope in the world
    [slope.sdf]
2026-08-12 - corrected to account for Gazebo's roll/pitch direction
    [slope.sdf]
2026-08-13 - adding battery weight to gazebo model preparation
    [batteryHolder-Body.stl, batteryHolder.FCStd, cubic_doggo.gazebo.xacro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]
2026-08-13 - quick change for imu direction
    [cubic_doggo.gazebo.xacro]
2026-08-13 - some CAD models were not updated
    [batteryHolder.FCStd, batteryHolder.stl]
2026-08-13 - quick CAD update
    [batteryHolder.FCStd, batteryHolder.stl]
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2026-08-14 - adding lidarHolder.stl
    [lidarHolder.stl]
2026-08-14 - adding all the main weights on the robot - update effort to 1.4 and friction parameters on the feet
    [cubic_doggo.gazebo.xacro, cubic_doggo.urdf.xacro, cubic_doggo_legB.xacro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]
2026-08-15 - some update to the world
    [slope.sdf]
2026-08-16 - some patching up for the Gazebo simulation
    [cubic_doggo.gazebo.xacro, cubic_doggo.urdf.xacro, cubic_doggo_legB.xacro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]
2026-08-16 - separate out the load to its own cubic_doggo_load.xacro, so that it's not repeated sim vs real
    [cubic_doggo.gazebo.xacro, cubic_doggo.urdf.xacro, cubic_doggo_load.xacro]
2026-08-16 - adding video of imu oscillatory behavior in Gazebo
2026-08-24 - initial launching Mujoco in ROS
    [cubic_doggo.mujoco.xacro]
2026-08-25 - reordering the mujoco urdf parser such that <keyframe> for joint position are applied after urdf inclusion in the xml file
    [cubic_doggo.mujoco.urdf, cubic_doggo.mujoco.xacro, cubic_doggo.mujoco.xml]
2026-08-26 - skip a redundance step
    [cubic_doggo.mujoco.urdf]
2026-09-02 - adding cubic_leg1 for debugging
    [cubic_leg1.mujoco.xml, cubic_leg1.urdf.xacro, cubic_legF.xacro]
2026-09-04 - 1 leg in mujoco configured
    [cubic_leg1.mujoco.xml, cubic_legF.xacro]
2026-09-04 - adding full robot in mujoco, control next
    [cubic_doggo.mujoco.xml]
2026-09-04 - adding imu in mujoco
    [cubic_doggo.mujoco.xml]
2026-09-04 - adding mujoco bridge for the ros2 commanded - it so far exploses into pretzel again
    [cubic_doggo.mujoco.xml]
2026-09-04 - at least the initial condition is settled - can't execute stand action yet however
    [cubic_doggo.mujoco.xml, cubic_doggo.urdf.xacro]
2026-09-06 - walking just fine in mujoco now
    [cubic_doggo.mujoco.xml]
2026-09-06 - publish velocity and effort as well - add a slope + testing imu directions
    [cubic_doggo.mujoco.xml]
2026-09-06 - correct the servo2 limits
    [cubic_doggo.mujoco.xml]
2026-09-06 - adding forest.png from https://www.gamedevmarket.net/asset/free-pixel-art-forest
    [cubic_doggo.mujoco.xml]
2026-09-06 - adjusting forest.png size
    [batteryHolder.FCStd]
2026-09-06 - some decorative work
    [cubic_doggo.mujoco.xml]
2026-09-08 - small aethetic adjustments
    [cubic_doggo.mujoco.xml]
2026-09-12 - initial cubic_doggo_mujoco_stand.py with Pinocchio
    [cubic_doggo.mujoco.xml]
2026-09-12 - still cannot get pinocchino to move correctly yet. Note however that the frame is important
2026-09-13 - print out body height from pinocchio calculation - log output on mujoco GUI screen - random stride direction
    [cubic_doggo.mujoco.xml]
2026-09-14 - adding ray cast height evaluation
    [cubic_doggo.mujoco_walk.xml]
2026-09-14 - some small adjustments
    [cubic_doggo.mujoco_walk.xml]
2026-09-19 - PPO init
    [cubic_doggo.mujoco_stand.xml]
2026-09-20 - some file naming organization
    [cubic_doggo.mujoco.ppo_stand.xml, cubic_doggo.mujoco_pinocchio.xml]
2026-09-20 - now can train with visualization and tensorboard tracking - but currently reward function can explode
    [cubic_doggo.mujoco.ppo_stand.xml]
2026-09-25 - improving cubic_doggo_mujoco_ppo_stand.py
    [cubic_doggo.mujoco.ppo_stand.xml]
2026-09-27 - forget to add relevant CAD models - adding curriculum scheduler - adding record on tensorboard for each reward components
    [XL430holderBasic.FCStd, XL430holderBasic.stl, XL430holderThighBack.FCStd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]
2026-09-29 - quick illustration things
    [cubic_doggo.mujoco.ppo_stand.xml]
2026-09-30 - updated a few CAD models
    [XL430holderBasic.FCStd, basePlate.FCStd, calfFeet.FCStd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]
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2026-10-03 - adding leg torque std as penalty to allow 4 legs on ground
2026-10-04 - randomizing the slope tilt init
    [cubic_doggo.mujoco.ppo_stand.xml]
2026-10-05 - single out the slope standing ppo as it's rather difficult to implement - adding random horrizontal force in the schedule currilum
    [cubic_doggo.mujoco.ppo_stand_slope.xml]
2026-10-06 - adding .cvs logger, so tee is not needed
    [cubic_doggo.mujoco.xml]
2026-10-09 - adding scheduler to tighten reward/penalty over steps - adding low pass filter to action
2026-10-11 - standing on the ground RL model looks good at the moment
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2026-10-24 - the onnx deployment in ROS2 commander now compiles and run, but has issue in the control loop - uploading the stand on fixed slope onnx file, okayish blancing, but often with 3 legs
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
